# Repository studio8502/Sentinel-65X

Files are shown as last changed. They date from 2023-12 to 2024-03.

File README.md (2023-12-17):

# Sentinel 65X

This is a design for an 8/16-bit computer/games console, which uses
the 65816 CPU architecture (by WDC) and the VERA video system (by
Frank van den Hoef) as its core. It is not directly compatible with
any existing system, but porting from other 6502 and 65816 systems
which have a similar architecture should not prove difficult.

## Features

- Designed to minimize BOM and construction costs
- Intended to be a turnkey "fabrication ready" design which anyone
  can produce and sell for any purpose
- Fully open source hardware designs, released under the CERN OHL
  (permissive) V2
- 8MHz WDC W65C265S CPU (W65C816S compatible)
  - 16MB adress space
  - 8 timers
  - Multiple priority-encoded interrupts
  - Built-in GPIO
- 512KB of on-board static RAM
- 512KB of flash ROM
- RGB video output at 640x480
- Stereo audio output
- SD card slot
- Dual enhanced SNES-compatible controller ports
  - Supports SNES controllers & joysticks
  - Supports the SNES mouse and clones
  - Enhanced with I2C bus support for custom peripherals
- Cartridge/expansion port with full system bus, supporting ROM,
  RAM, and I/O expansions
- Amiga-inspired "clock port" which also serves as a debug port

## Hardware

The revision 0 schematic is nearly finished, approaching the production
of the first working prototypes. The goal is a limited release in 2024,
followed by a full release in 2025.

## Software

At the present time, software for this design is nonexistent. The
intention is to implement a kernel and library to support assembly
and C programming for cross-development (using the Calypsi C toolchain),
and to eventually develop or port a suite of tools for on-device
programming to be put into the system ROM.

The planned kernel will be reminiscent of the architecture of MSX-DOS
2, but will support long file names and the FAT32 (and later ExFAT)
filesystem on SD cards.

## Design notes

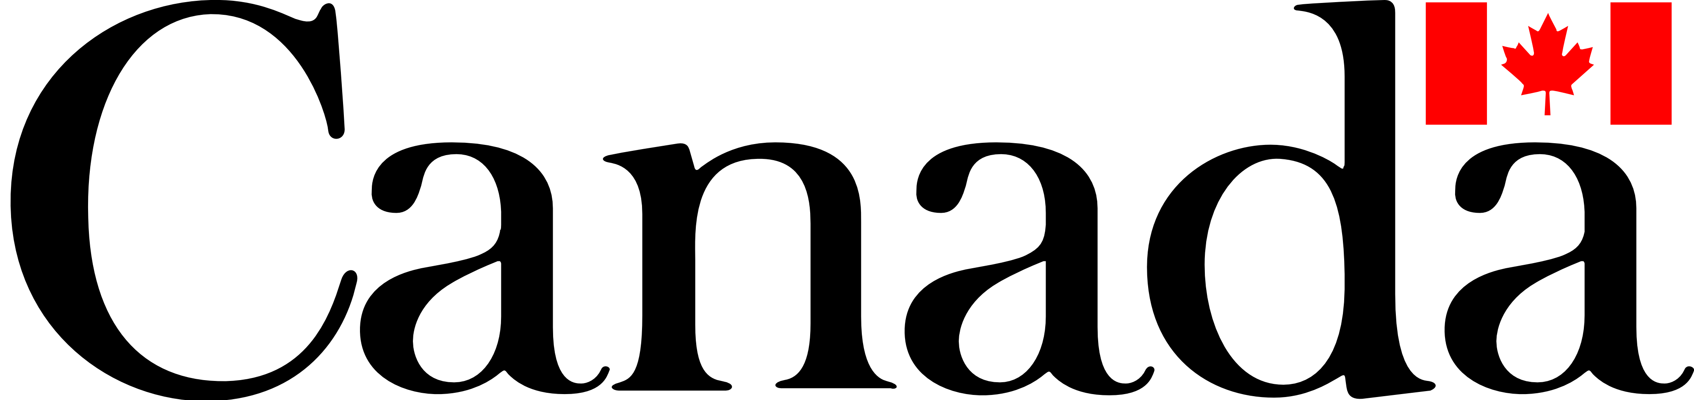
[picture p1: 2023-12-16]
Images/Canada_wordmark.png

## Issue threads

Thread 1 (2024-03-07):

Sentinal 65X - Prototype 4 Review

gsuberland, 2024-03-07:
## USB Power & Data (U7 / U8)

U8 appears to be improperly configured, with both 3V3OUT and U7 driving the +3.3V rail simultaneously. I suspect you were trying to set up the self-powered configuration in the FT230XS datasheet and accidentally connected 3V3OUT to the +3.3V rail instead of its own net. Based on the datasheet you probably want to connect 3V3OUT, VCCIO, and RESET together and then to a 100nF cap to ground. I suspect this is what C23 was initially supposed to be for. C23's +3.3V pad is also disconnected in the PCB design.

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

Decoupling on U8 is missing - should be 2x 100nF and 1x 4.7uF, all MLCCs as per Figure 6.2 of the datasheet.

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

The 27R series termination resistors on USB D+/D- lines are missing. See FT230X datasheet.

The FT230XS has a small amount of ESD protection so you can probably get away without any discrete ESD protection IC, but a TVS clamp on +5V (VBUS) wouldn't hurt.

The regulator layout is kinda loose and you've got pretty long loops with decoupling caps quite far from the things they're decoupling. There was also quite a bit of sketchy routing going on around there with non-ground stuff on the ground layer and unnecessary layer changes. I took the liberty of doing a bit of a tidy-up here since it was easier than trying to go through the details. Before and after:

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

Essentially I moved the caps closer to the things being decoupled, shifted the +5V trace from VBUS up and the 3.3V regulator right so the power traces are kept away from the USB D+/D- traces (and so the pins have a straight shot to the regulator input caps), did a similar thing with the output caps, then shortened the D+/D- traces significantly and eliminated the layer change on those signals, got rid of the 3V3 trace on the ground layer, and moved the D+/D- crossover trace under the connector to use F and In2 so the ground plane doesn't get broken and both stay referenced to the ground plane on In1. I've left the D-/D+ signals disconnected since you need to add the 27R termination resistors. Also note that I've left C23 in place as if it's a decoupling cap but you'll want to rework that when you fix the 3V3OUT stuff and add the three decoupling caps to U8.

I've attached the tweaked KiCad files :)

## Data lines

Wherever possible, each via that moves a signal from F or In1 to In3 or B should be accompanied by a ground stitching via placed as close as possible to that via, since the reference plane is changing from In1 to In4. This allows return currents to flow between the two ground planes, and provides a reference plane in the z-axis.

For example, all of these vias go from In2 to In3, which means the ground reference plane swaps from In1 to In4:

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

And here's how I'd add the reference vias: (sharing a ref via is fine)

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

## Processor

+3.3V pins on the east and south could be routed directly to the decoupling caps. East has a direct route without changing anything. South can be routed directly by shifting the RES trace down slightly.

I'd also consider swapping those 100nF caps for CL05A106MQ5NUNC (10uF 6.3V 0402). They're on JLCPCB Basic Parts, under half a cent each. After derating to 3.3V DC bias it's about 3.5uF. At 8MHz the caps have about 18mΩ of impedance, which is nice and low, mostly due to the smaller package size having lower inductance.

## Main RAM

C14 decoupling cap should be moved closer to the +3.3V pin. Again maybe upgrade to CL05A106MQ5NUNC.

## System ROM

Maybe upgrade C12 to CL05A106MQ5NUNC.

## SD Card Slot

If you're swapping other caps to CL05A106MQ5NUNC, you can save a BOM line by swapping C8 as well.

## Clock Generation

Again, probably CL05A106MQ5NUNC on the decoupling. Ideally move the caps so they sit across the +3.3V and GND pins on the ICs, rather than putting vias under the IC pads and under the cap pads.

For example, from this:

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

We can do this:

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

## VERA Graphics System

Missing decoupling on 5V output.

## Cartridge Port

Missing decoupling on 3.3V or 5.0V lines.

## Expansion Port

Missing decoupling on 3.3V or 5.0V lines.

## Clock Port

Missing decoupling on 3.3V line.

## Video DAC & Outputs

Missing decoupling on 3.3V line.

Unnecessary layer change on HSYNC line, could be routed all on In2.

## Audio DAC & Output

Missing decoupling caps. Probably some on the module, but I'd stick a 10uF MLCC on the 5V line anyway.

Are A3V3 and AGND disconnected on purpose? The PCM5102 IC datasheet shows them connected to +3.3V and ground, but maybe there's something specific about the GY-PCM5102 module board I don't know?

## Controller Ports

Missing decoupling caps.

## Glue Logic

Atmel appnote 0484C–09/99 recommends 220nF capacitance with 4nH parasitic inductance at most, so a pair of 100nF 0805s are probably not gonna cut it. I'd recommend replacing C14/C15 for a single CL05B224KO5NNNC 220nF 16V 0402 capacitor.

joelpmichael, 2024-03-08:
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

I'm still not liking the smell of this section. I've seen problems with a UART's 3V3 LDO line hooked to the host board's 3V3 rail, where a sudden current use spike reliably caused the UART to crash.  In this case it may not be a problem due to VCC being 3.3V (the board I had an issue with had VCC connected to USB-VBUS in parallel with a 3.3V LDO), but if anything it would be more correct to use USB-VBUS directly to power the UART because there's no other power supply for the UART (yet?)

You may want to go back to the LM1085 from V4 as the voltage regulator between USB-VBUS and 3V3, because it has a higher current rating than a '1117 and it saves you a BOM line.  Alternatively, you could do something like add a buck regulator to v4's power input to bring that down to about 5V (and avoid a lot of heat from the 5V LDO), and power diodes between USB-VBUS and the buck-regulated 5V rail.

gsuberland, 2024-03-08:
Additional thoughts:

## 3V3OUT

Good idea to use 0R / jumper footprints to give you the option to revert it back to the tie-to-ground instead of tie-to-3V3 appreoach. That way if it doesn't work you don't need a respin.

## Voltage Regulators

The 10uF input cap is at the absolute limit of the USB spec for bus capacitance. If it's got 20% tolerance, you're potentially exceeding the spec. If it's a cheaper cap with -20%/+80% tolerance, you're potentially vastly exceeding the spec. I'd recommend swapping it for a 4.7uF electrolytic or tantalum. Probably not best to use an MLCC because its very low ESR means higher inrush current and potential resonance issues when combined with the USB cable's inductance, but you can probably get away with it fine as long as you don't want to sell this as a product (where it'll need to pass EMC).

The 10uF electrolytic output cap is probably not the best choice now I've had time to mull it over. A pair of 10uF tantalum caps (TAJA106K016RNJ) are a better option, or you could go with a pair of the 10uF MLCCs I recommended (which would be cheaper). This choice gets a bit tricky because AMS1117, LM1117, and AP1117 have different behaviours on this front. Check your LDO's datasheet to see if it mentions being stable with MLCCs only, and what the specific decoupling advice is. AMS1117, for example, says 22uF tantalum is ideal, so 2x 10uF tantalum should be fine. Often LDO vendors recommend doubling the capacitance (e.g. 47uF instead of 22uF) if you're using electrolytics, but you should follow datasheet / appnote guidance here.

## Video DAC

The UPduino IOs are used to drive the resistor ladder DAC, but those resistances are quite low so the IO current might be excessive for the FPGA. I wasn't able to find any IO current limit specs for the ICE40UP5K, so I'm not 100% sure. However, in the worst case (input lines 0, 1, and 2 low, and line 3 high, and assuming worst-case 5% tolerance on the resistors) the draw will be 5.47mA with 5V IO or 3.61mA with 3.3V IO. In the absence of information showing that the FPGA can handle that much IO current, it would be a good idea to use a buffer IC (a pair of hex CMOS buffers would do it) on the R0-R3, G0-G3, and B0-B3 lines to ensure that the IOs can provide enough current.

I'm not sure what frequency you're updating the DAC input signals at, so make sure the buffer IC is rated for it. Most modern CMOS buffer ICs should be fine.

It's also worth adding opamp buffers on the red, green, and blue outputs. This will make the outputs immune to leakage current, so you'll get correct R/G/B voltage levels on the SVGA output regardless of what display you plug in. Make sure the opamps are RRIO (rail-to-rail input and output) capable (or at least capable of going right down to 0V), and unity gain stable. Make sure the opamps have sufficient bandwidth and slew rate for the signal update rate.

If you have space, it might be worth adding a separate LDO for powering the output opamps, to make sure they have a nice clean rail. Again follow the decoupling advice on the LDO datasheet. You can get away without this but it adds peace of mind.

I'm also not a fan of the naming of the RGB signals, 'cos R2 (the signal) and R2 (the part) are ambiguous. Maybe prefix the signals with V, e.g. VR1.

## USB IOs

Not sure about those 270R on the TXD/RTS lines. I don't see them in the datasheet and I'm not sure what purpose they serve here.

Might be worth adding [the TX/RX swap footprint trick](https://hachyderm.io/@mwbrown/111903245384095180) to both the TXD/RXD lines on the MCU side and the D+/D- lines on the USB connector side. Use 0603 or 0402 on the D+/D- side to avoid a large impedance discontinuity.

# General

There's a lack of testpoints on the PCB. Don't forget to add them for easier debug. I also like adding a large plated ground pad right on the edge of the board somewhere, top and bottom, connected to ground, so I can clip a crocodile clip to the edge of the board really easily while probing.

I also recommend separating critical power and signal paths with SMD jumper pads or 0R footprints at the boundary between different blocks of the circuit. This allows you to isolate and test each block of the circuit sequentially and catch / debug issues early instead of just powering the lot on and praying for no magic smoke. For example I might add a 0R between VUSB and the LDO input, and then again between the LDO and the 3V3 rail. Wherever you think you might benefit from being able to turn one thing on at once, or disable something, or disconnect some signal for debugging. This also allows you to stick a shunt resistor inline with the voltage rails if you want to measure the rail current.

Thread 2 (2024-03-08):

Repo incompability with Windows

joelpmichael, 2024-03-08:
Error while checking out repo due to `:` being a reserved character in file paths on Windows.

```
$ git clone https://github.com/studio8502/Sentinel-65X.git
Cloning into 'Sentinel-65X'...
remote: Enumerating objects: 406, done.
remote: Counting objects: 100% (224/224), done.
remote: Compressing objects: 100% (157/157), done.
remote: Total 406 (delta 73), reused 212 (delta 63), pack-reused 182
Receiving objects: 100% (406/406), 133.68 MiB | 12.91 MiB/s, done.
Resolving deltas: 100% (156/156), done.
error: invalid path 'kicad/A:V Boards/DVI (256 colours) + Stereo Miniplug/DVI (2
56 colours) + Stereo Miniplug-backups/DVI (256 colours) + Stereo Miniplug-2024-0
2-26_213444.zip'
fatal: unable to checkout working tree
warning: Clone succeeded, but checkout failed.
You can inspect what was checked out with 'git status'
and retry with 'git restore --source=HEAD :/'
```

You may want to add .DS_Store to your .gitignore too.

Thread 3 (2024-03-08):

Prototype 3/4/4A review

joelpmichael, 2024-03-08:
As commented in #1 you should think more about your overall power supply now that you're also adding USB power, including making sure you aren't back-powering either the barrel jack (J10 in V4) or USB-VBUS if both are connected.  I've used this setup successfully:
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

The other potential issue I can see, that's been repeated over the entire design, is that connector shields are not grounds if there's ground pins inside the connector! [Microchip AN2587](https://www.microchip.com/en-us/application-notes/an2587-1.html) is a good place as any to start when diving down this infinite chasm, specifically section 12.3. The (ex-Atmel) Microchip SAM datasheets also contain an excellent schematic checklist, including a checklist item about ESD protection.  The [SAML21 Family Datasheet](https://ww1.microchip.com/downloads/aemDocuments/documents/MCU32/ProductDocuments/DataSheets/SAM-D21-DA1-Family-Data-Sheet-DS40001882H.pdf) section 45.8 discusses ESD and correct grounding protection of USB connectors. This is part of the same system with the example buck-boost regulator, and includes a dedicated (yet extremely cheap because it's so common) USB ESD protection system:
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

KyleCardoza, 2024-03-08:
Far as the first bit goes, there won't be a barrel jack to back-power, so no worries there. I will look at that recommended documentation, but have already fixed the shield bit, I think:

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

KyleCardoza, 2024-03-08:
(ignore that disconnected D+ line, I just fixed it)

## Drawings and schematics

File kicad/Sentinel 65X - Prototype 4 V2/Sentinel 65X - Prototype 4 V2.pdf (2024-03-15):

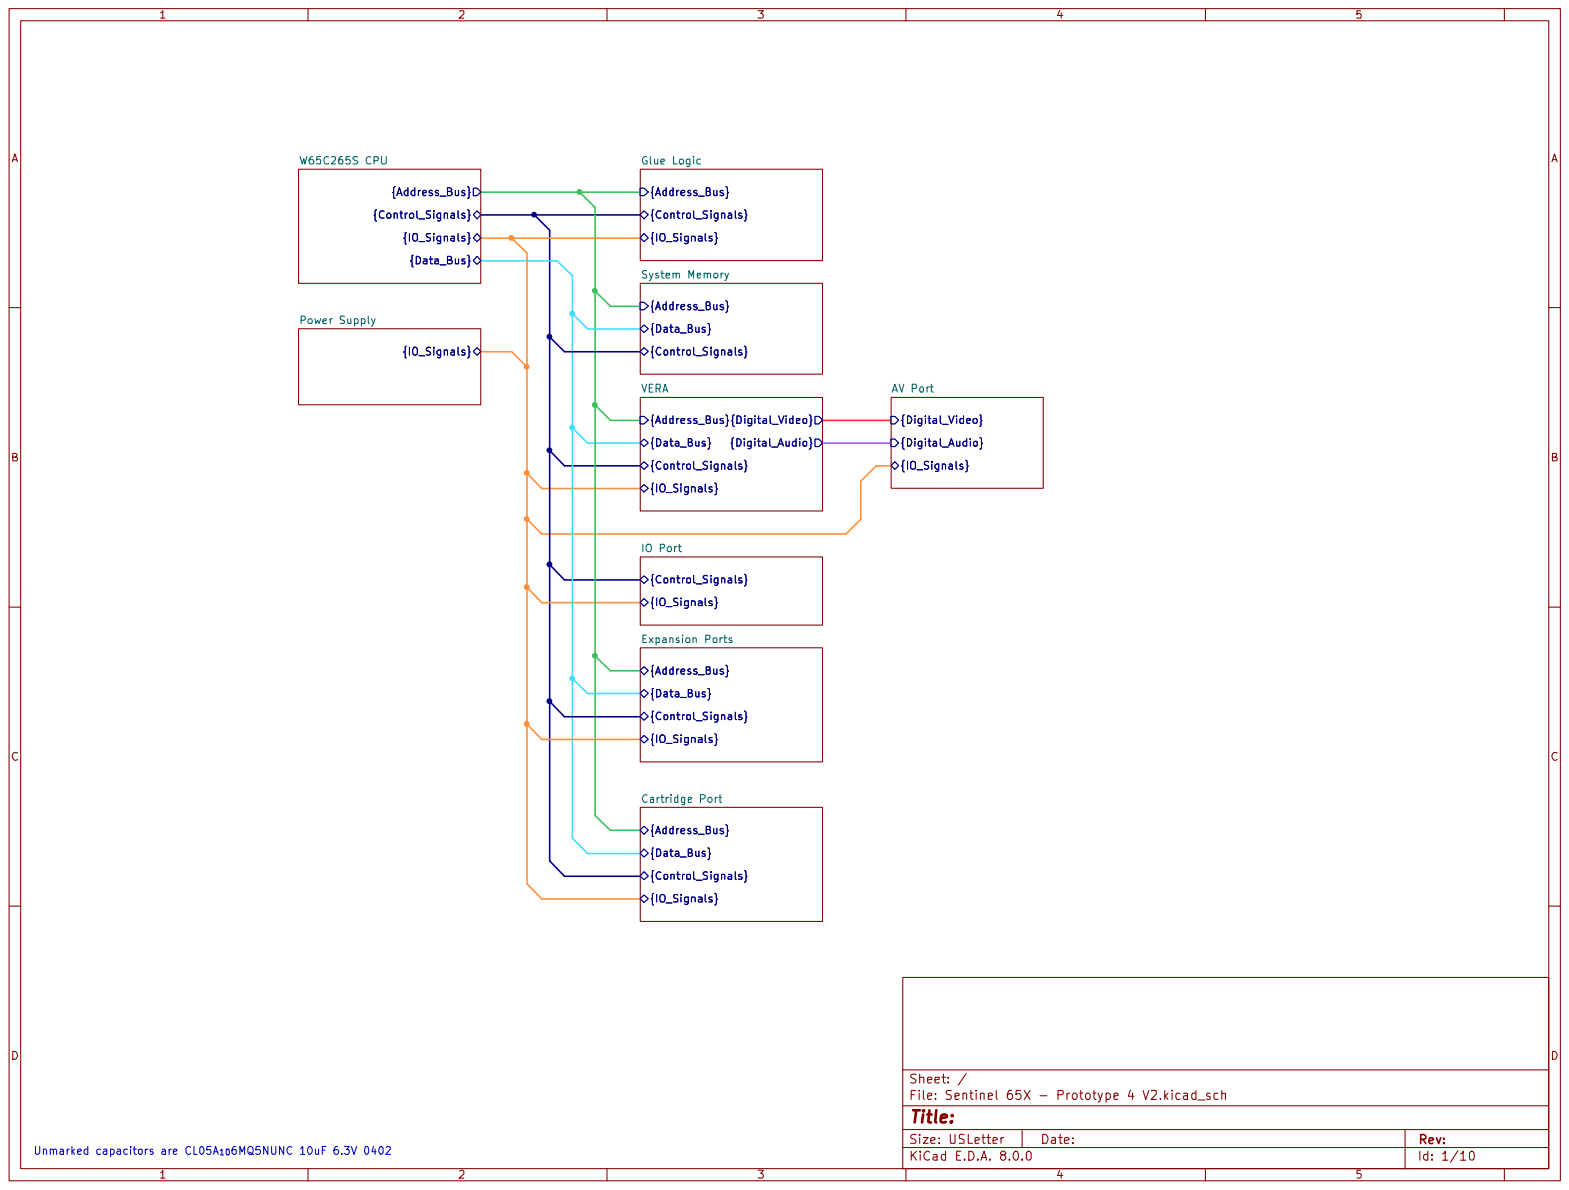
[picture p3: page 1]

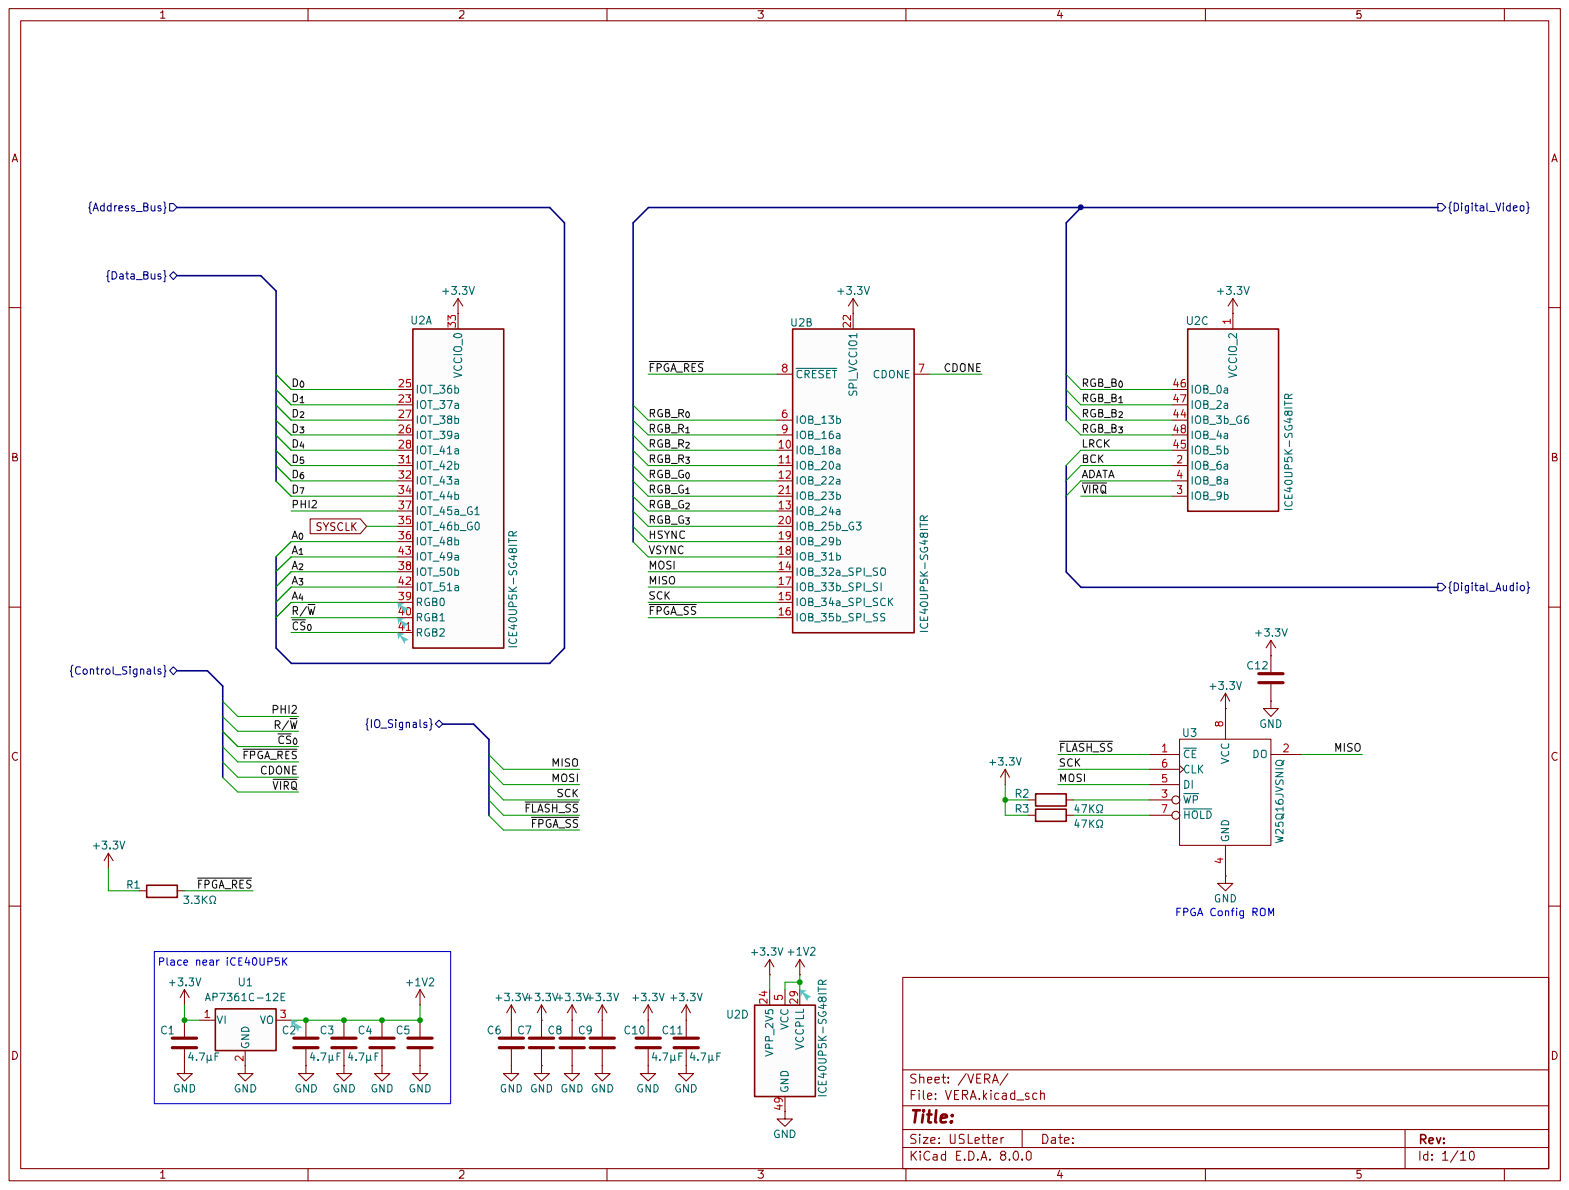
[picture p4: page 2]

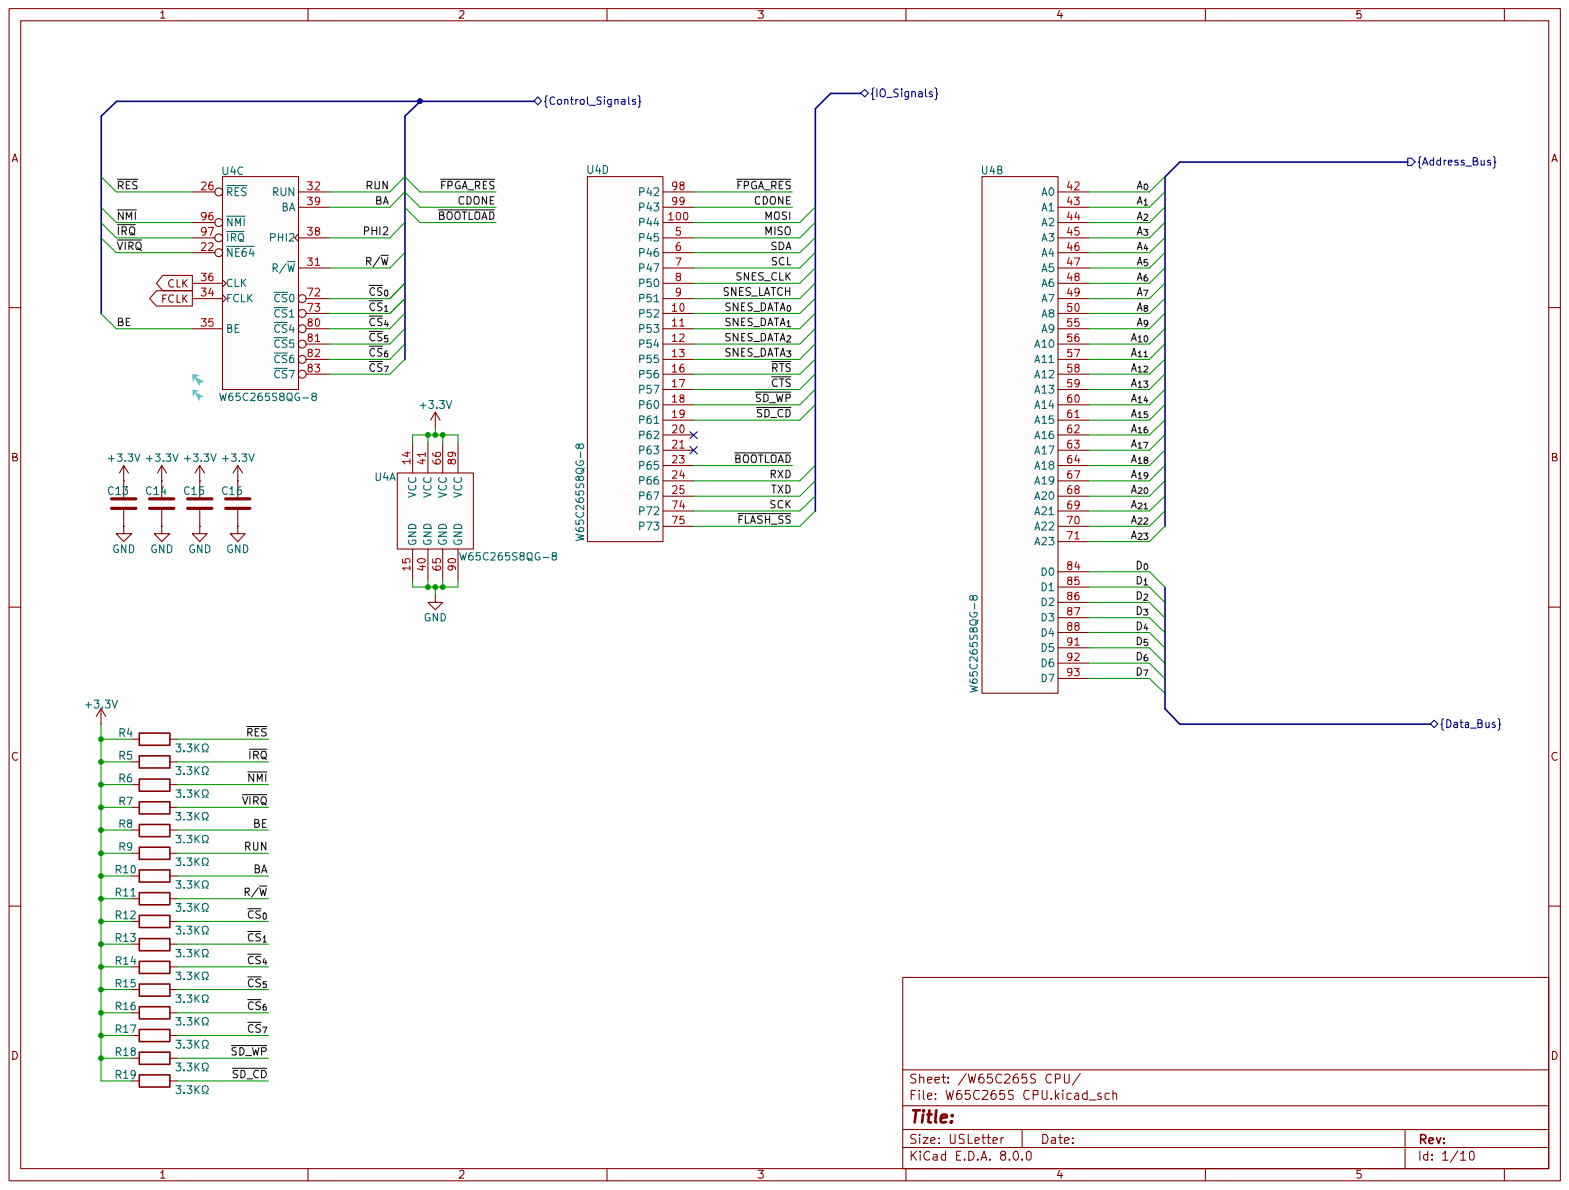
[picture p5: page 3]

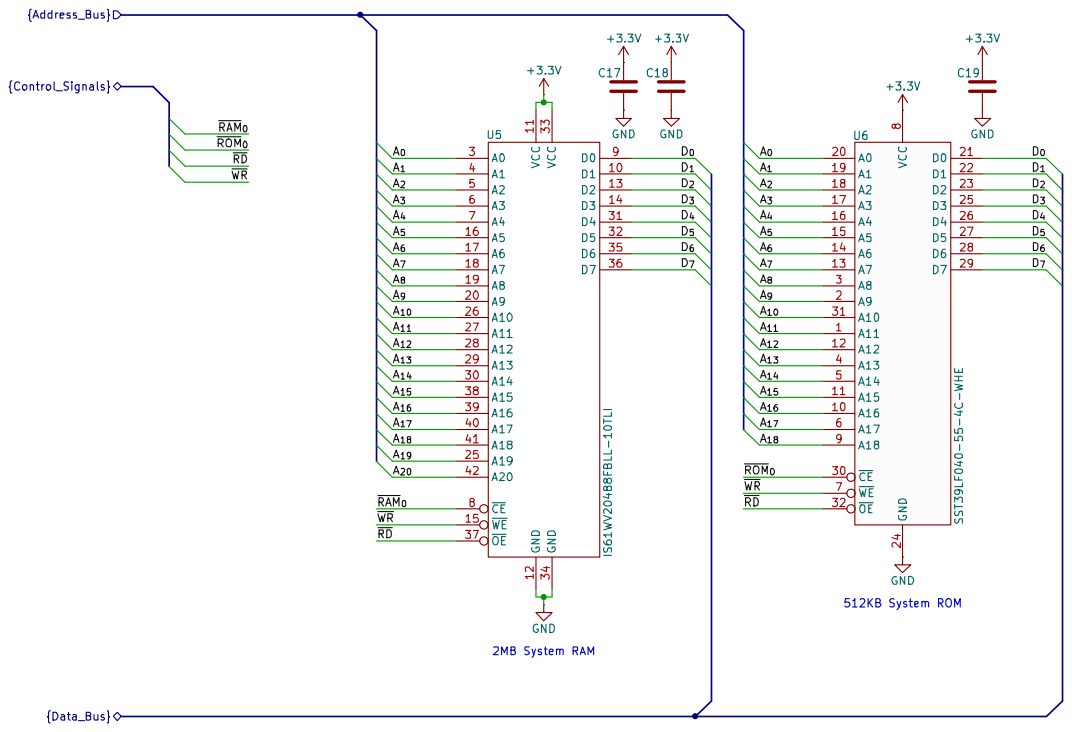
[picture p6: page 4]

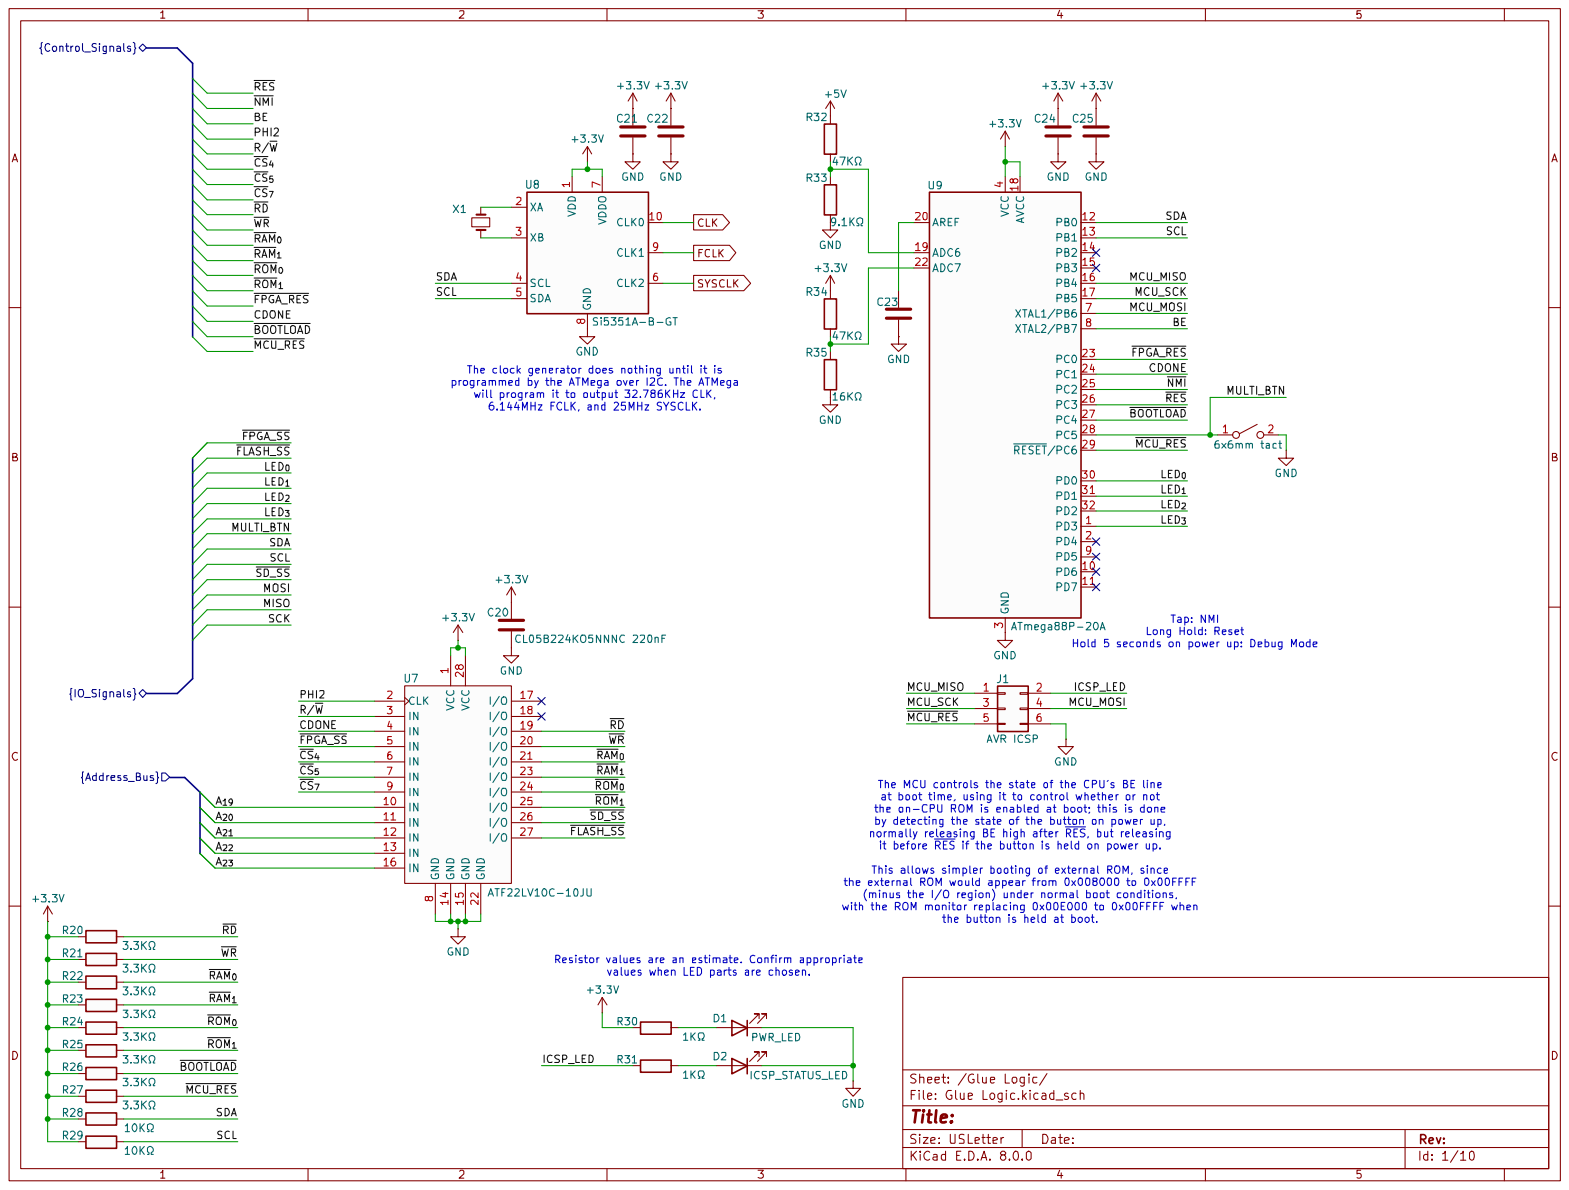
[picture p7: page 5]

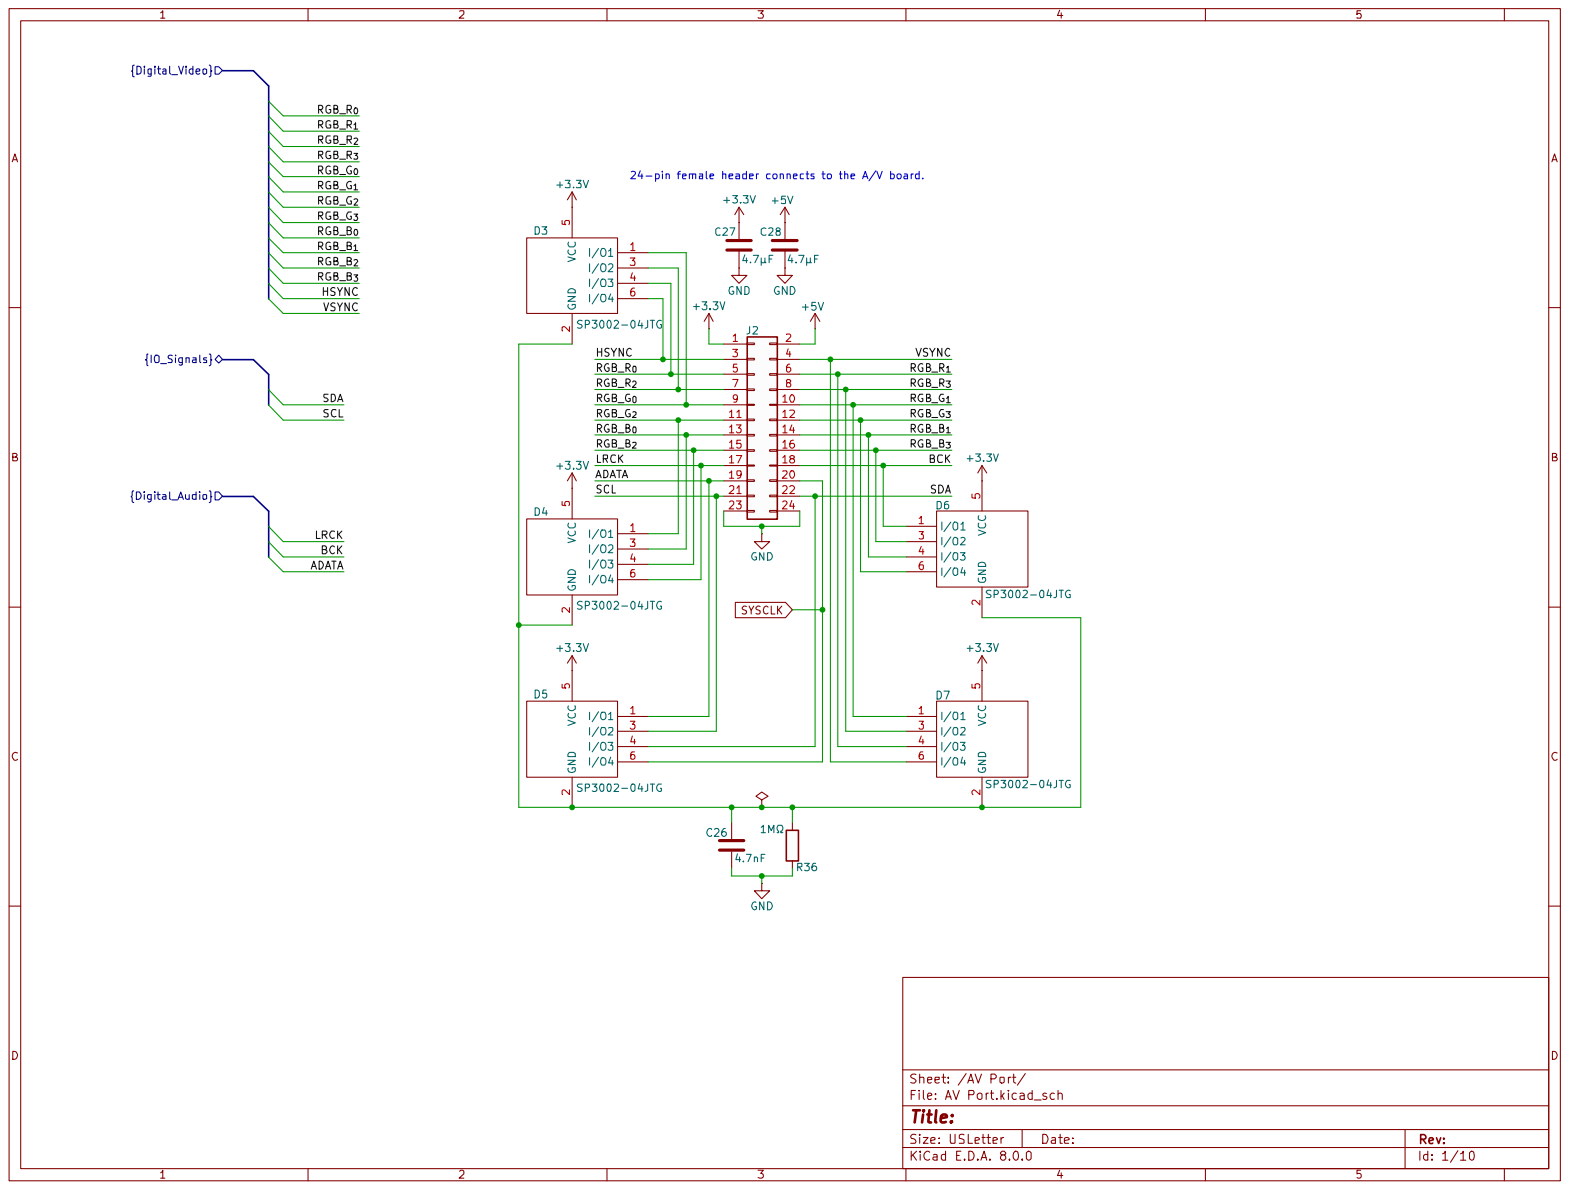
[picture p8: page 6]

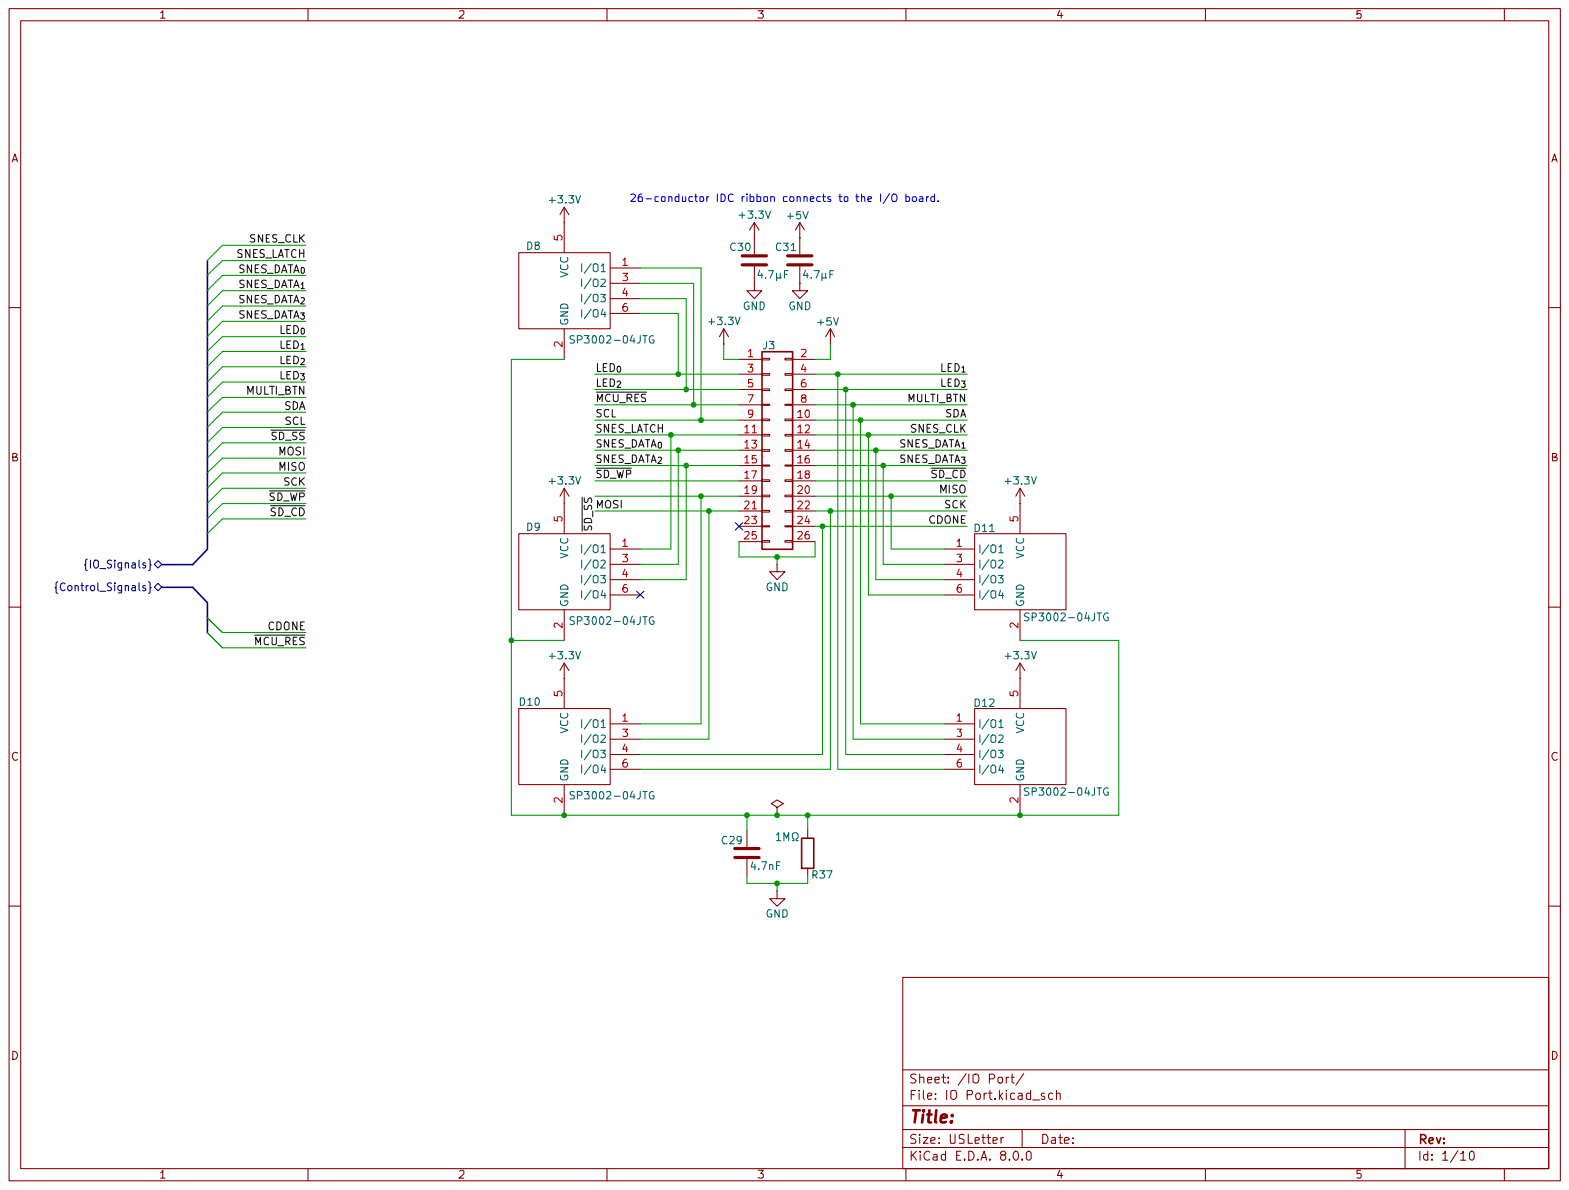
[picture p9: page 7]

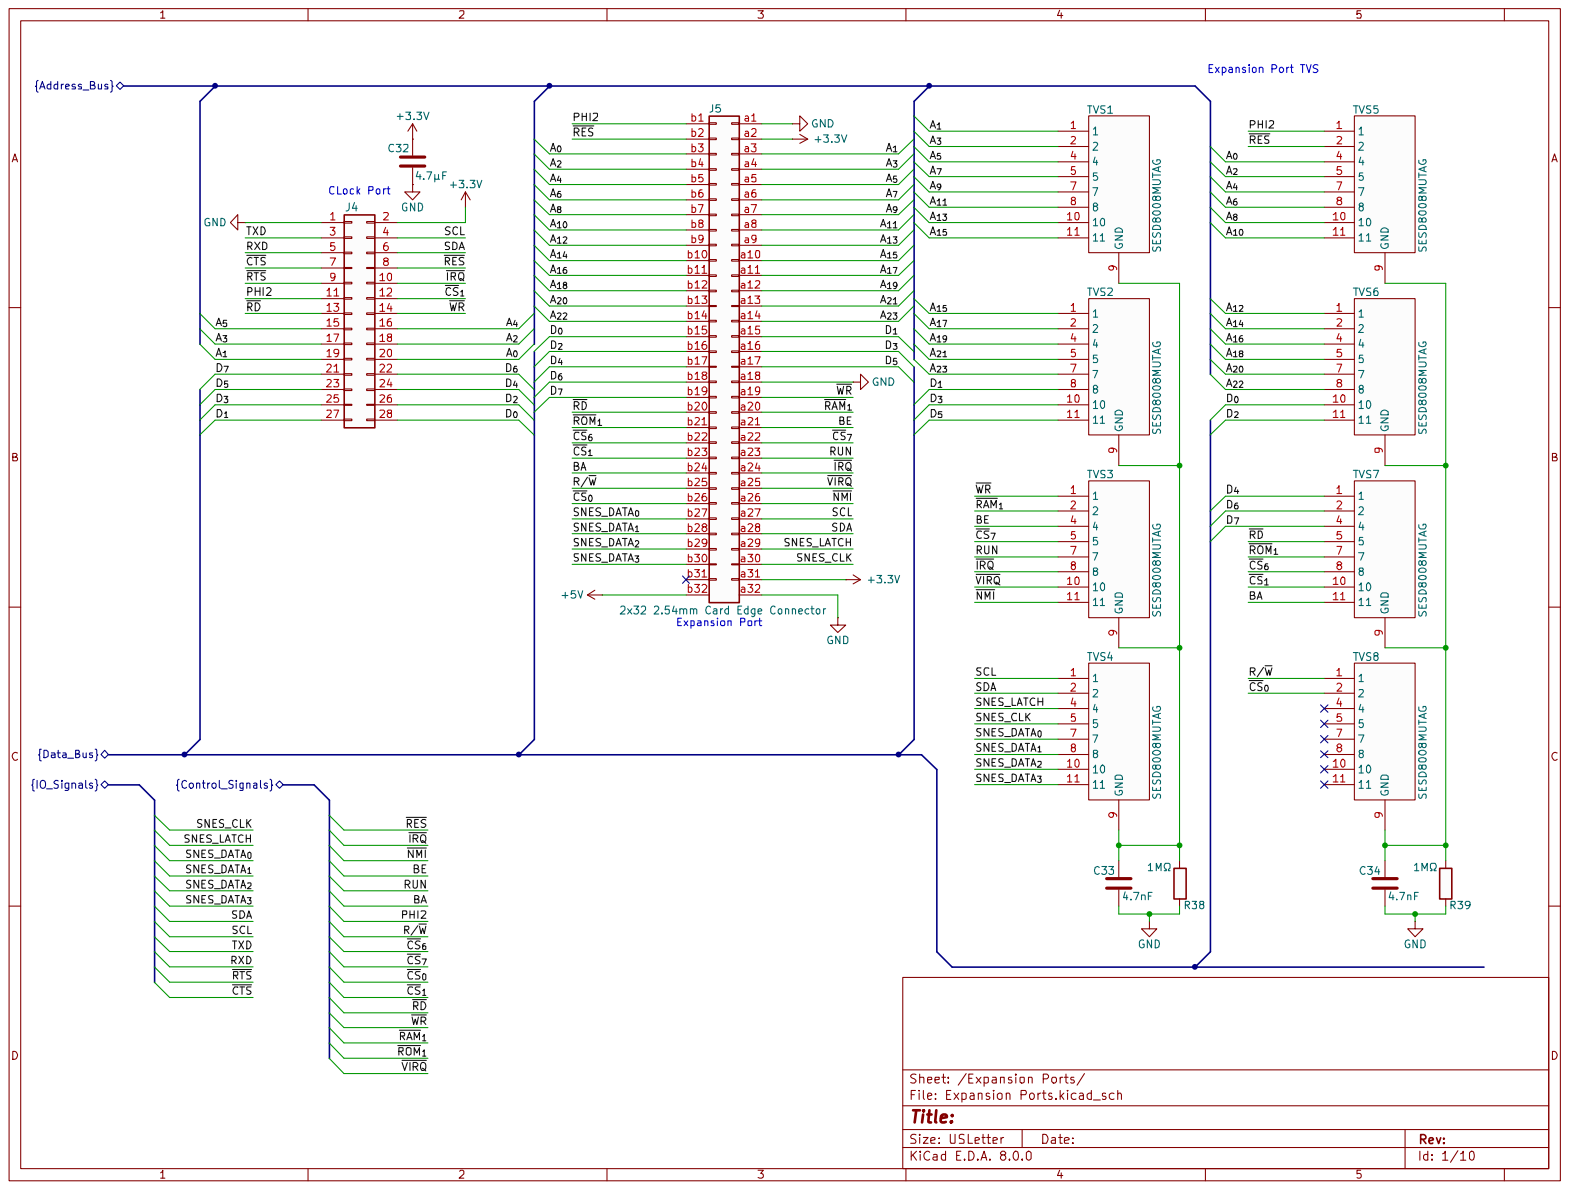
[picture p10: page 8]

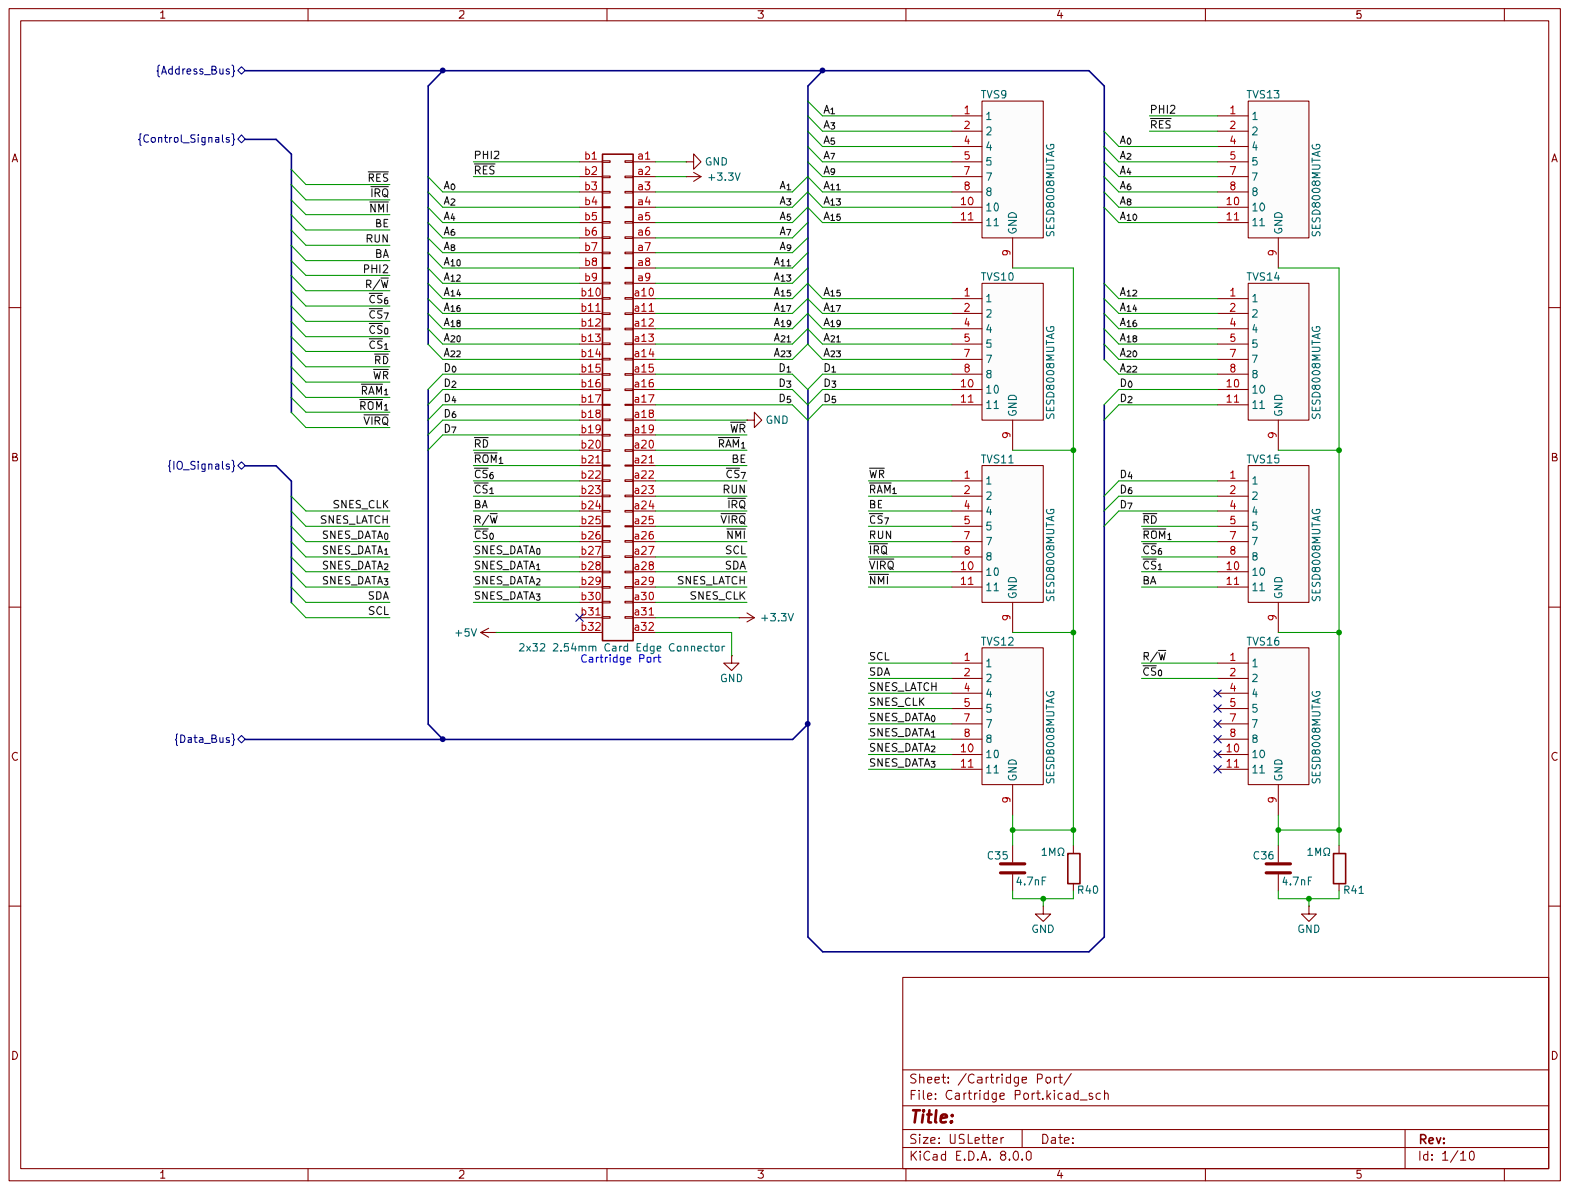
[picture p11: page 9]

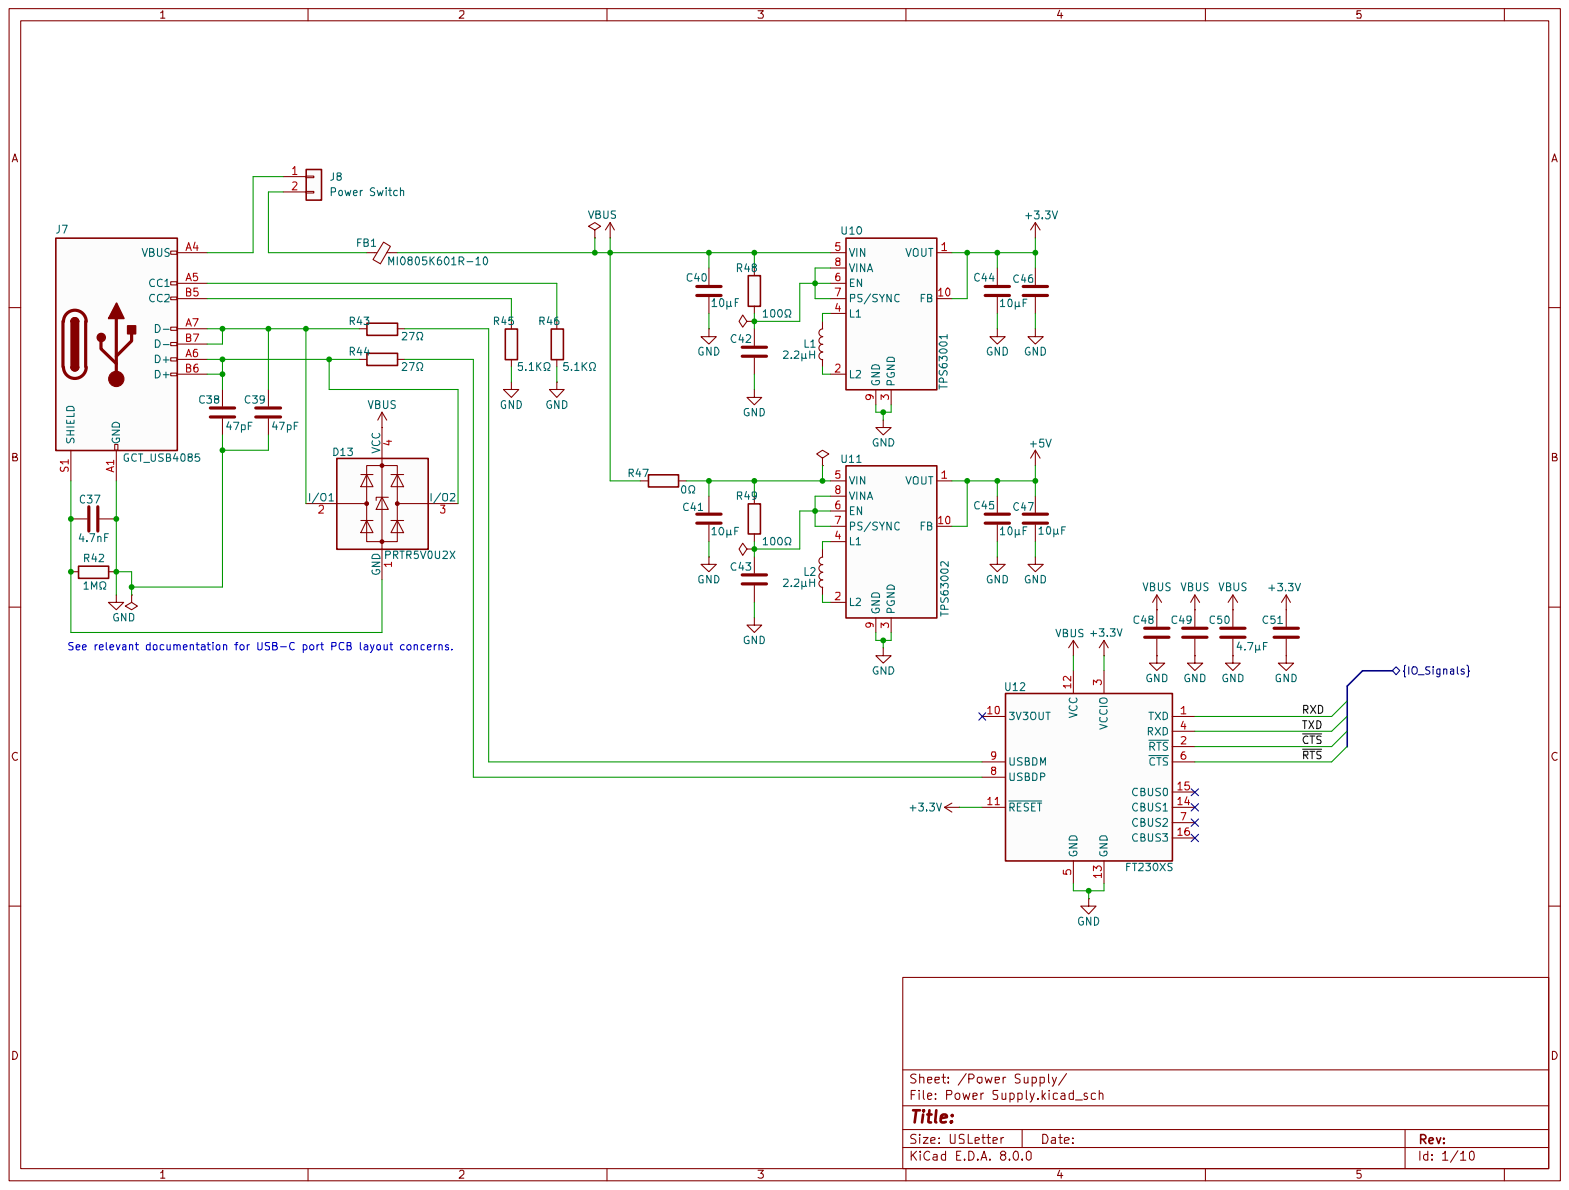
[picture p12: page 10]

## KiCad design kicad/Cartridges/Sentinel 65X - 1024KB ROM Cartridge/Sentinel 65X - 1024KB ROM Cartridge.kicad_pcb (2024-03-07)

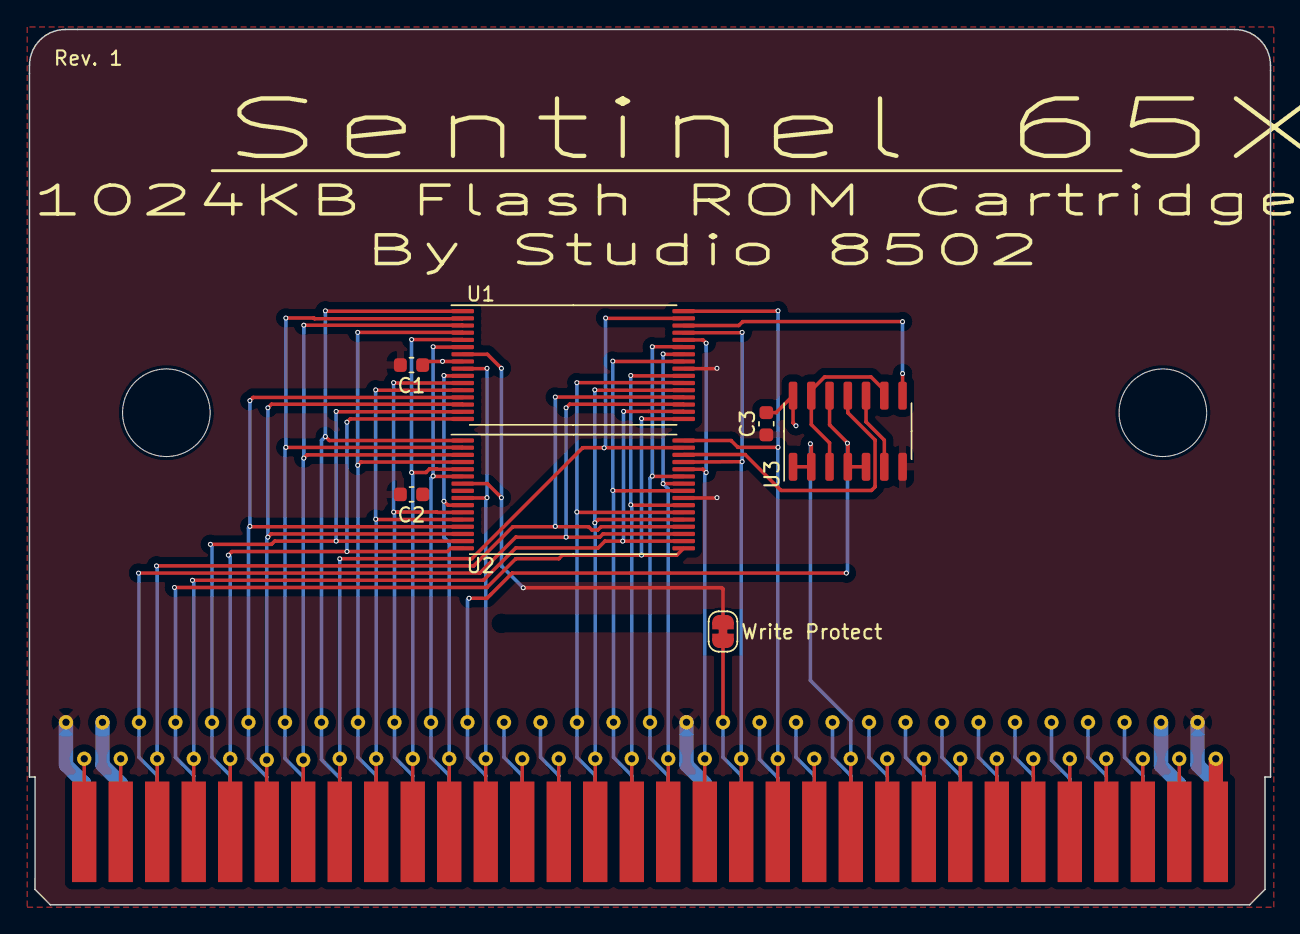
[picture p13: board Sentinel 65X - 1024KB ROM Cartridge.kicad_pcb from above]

Board: 2 copper layers, 86.4 x 60.9 mm, 8 parts (0 on the bottom side), 38 nets.

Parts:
C1, C2, C3: 100nF; C_0603_1608Metric
J1: 2x32 2.54mm Card Edge Connector; Conn_Edge_2x32_THT_2.54mm_Male
JP1: SolderJumper_2_Bridged; SolderJumper-2_P1.3mm_Bridged_RoundedPad1.0x1.5mm
U1, U2: TSOP-I-32_14.4x8mm_P0.5mm
U3: 74LS00; SOIC-14_3.9x8.7mm_P1.27mm

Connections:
+3.3V: C1.1, C2.1, C3.1, J1.a2, J1.a31, U1.8 (VDD), U2.8 (VDD), U3.14 (VCC)
/A0: J1.b30, U1.20 (A0), U2.20 (A0)
/A1: J1.a30, U1.19 (A1), U2.19 (A1)
/A2: J1.b29, U1.18 (A2), U2.18 (A2)
/A3: J1.a29, U1.17 (A3), U2.17 (A3)
/A4: J1.b28, U1.16 (A4), U2.16 (A4)
/A5: J1.a28, U1.15 (A5), U2.15 (A5)
/A6: J1.b27, U1.14 (A6), U2.14 (A6)
/A7: J1.a27, U1.13 (A7), U2.13 (A7)
/A8: J1.b26, U1.3 (A8), U2.3 (A8)
/A9: J1.a26, U1.2 (A9), U2.2 (A9)
/A10: J1.b25, U1.31 (A10), U2.31 (A10)
/A11: J1.a25, U1.1 (A11), U2.1 (A11)
/A12: J1.b24, U1.12 (A12), U2.12 (A12)
/A13: J1.a24, U1.4 (A13), U2.4 (A13)
/A14: J1.b23, U1.5 (A14), U2.5 (A14)
/A15: J1.a23, U1.11 (A15), U2.11 (A15)
/A16: J1.b22, U1.10 (A16), U2.10 (A16)
/A17: J1.a22, U1.6 (A17), U2.6 (A17)
/A18: J1.b21, U1.9 (A18), U2.9 (A18)
/A19: J1.a21, U3.4, U3.5, U3.12
/D0: J1.b18, U1.21 (D0), U2.21 (D0)
/D1: J1.a18, U1.22 (D1), U2.22 (D1)
/D2: J1.b17, U1.23 (D2), U2.23 (D2)
/D3: J1.a17, U1.25 (D3), U2.25 (D3)
/D4: J1.b16, U1.26 (D4), U2.26 (D4)
/D5: J1.a16, U1.27 (D5), U2.27 (D5)
/D6: J1.b15, U1.28 (D6), U2.28 (D6)
/D7: J1.b14, U1.29 (D7), U2.29 (D7)
/~CS6: J1.b11, U3.1, U3.2
/~RD: J1.b13, U1.32 (~OE), U2.32 (~OE)
/~ROMH: U2.30 (~CE), U3.11
/~ROML: U1.30 (~CE), U3.8
/~WR: JP1.2 (B), U1.7 (~WE), U2.7 (~WE)
GND: C1.2, C2.2, C3.2, J1.a1, J1.a15, J1.a32, U1.24 (GND), U2.24 (GND), U3.7 (GND)
unnamed: J1.a14, JP1.1 (A)
unnamed: U3.6, U3.10
unnamed: U3.3, U3.9, U3.13

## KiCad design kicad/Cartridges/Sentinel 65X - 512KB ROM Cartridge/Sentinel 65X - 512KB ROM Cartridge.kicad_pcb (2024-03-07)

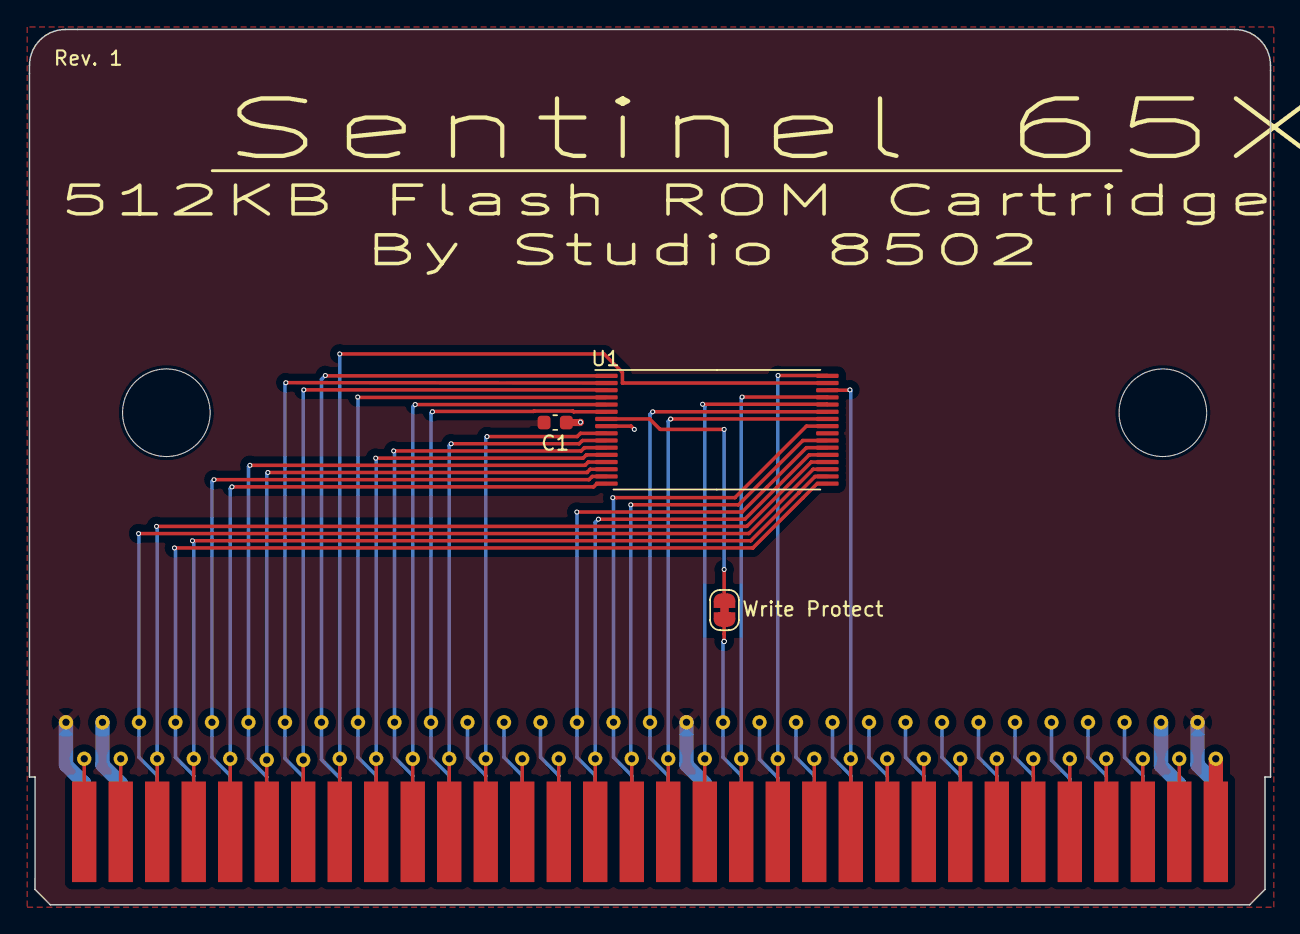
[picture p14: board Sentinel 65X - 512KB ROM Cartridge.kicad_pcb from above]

Board: 2 copper layers, 86.4 x 60.9 mm, 4 parts (0 on the bottom side), 33 nets.

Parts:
C1: 100nF; C_0603_1608Metric
J1: 2x32 2.54mm Card Edge Connector; Conn_Edge_2x32_THT_2.54mm_Male
JP1: SolderJumper_2_Bridged; SolderJumper-2_P1.3mm_Bridged_RoundedPad1.0x1.5mm
U1: TSOP-I-32_14.4x8mm_P0.5mm

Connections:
+3.3V: C1.1, J1.a2, J1.a31, U1.8 (VDD)
/A0: J1.b30, U1.20 (A0)
/A1: J1.a30, U1.19 (A1)
/A2: J1.b29, U1.18 (A2)
/A3: J1.a29, U1.17 (A3)
/A4: J1.b28, U1.16 (A4)
/A5: J1.a28, U1.15 (A5)
/A6: J1.b27, U1.14 (A6)
/A7: J1.a27, U1.13 (A7)
/A8: J1.b26, U1.3 (A8)
/A9: J1.a26, U1.2 (A9)
/A10: J1.b25, U1.31 (A10)
/A11: J1.a25, U1.1 (A11)
/A12: J1.b24, U1.12 (A12)
/A13: J1.a24, U1.4 (A13)
/A14: J1.b23, U1.5 (A14)
/A15: J1.a23, U1.11 (A15)
/A16: J1.b22, U1.10 (A16)
/A17: J1.a22, U1.6 (A17)
/A18: J1.b21, U1.9 (A18)
/D0: J1.b18, U1.21 (D0)
/D1: J1.a18, U1.22 (D1)
/D2: J1.b17, U1.23 (D2)
/D3: J1.a17, U1.25 (D3)
/D4: J1.b16, U1.26 (D4)
/D5: J1.a16, U1.27 (D5)
/D6: J1.b15, U1.28 (D6)
/D7: J1.b14, U1.29 (D7)
/~CS6: J1.b11, U1.30 (~CE)
/~RD: J1.b13, U1.32 (~OE)
/~WR: J1.a14, JP1.1 (A)
GND: C1.2, J1.a1, J1.a15, J1.a32, U1.24 (GND)
unnamed: JP1.2 (B), U1.7 (~WE)

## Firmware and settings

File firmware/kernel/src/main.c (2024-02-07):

//*****************************************************************************
//  Turaco-DOS
//
//  src/kernel/main.c
//*****************************************************************************

#include "config.h"
#include "turaco.h"

#include "kernel/device.h"

void
main(void)
{
	device_init_all();

	for (;;) {}
}

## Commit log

2023-12-06 Initial import of work in progress
    [Sentinel 65.kicad_pcb, Sentinel 65.kicad_sch, cpu.kicad_sch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]
2023-12-07 More work in progress
    [Sentinel 65.kicad_sch, audio_output.kicad_sch, io_connectors.kicad_sch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]
2023-12-14 Catchup to Rev0, V2
    [Sentinel 65 V2.kicad_pcb, Sentinel 65 V2.kicad_sch, Sentinel 65.kicad_pcb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]
2023-12-14 Added PDF of schematic
    [Sentinel 65 V2.kicad_sch]
2023-12-14 Added datasheets and manuals
    [Sentinel 65 V2.kicad_sch]
2023-12-15 Pinouts updated
    [Sentinel 65 V2.kicad_sch]
2023-12-16 Added audio mixing of cartridge audio
    [Sentinel 65 V2.kicad_sch]
2023-12-16 logo import
    [Sentinel 65 V2.kicad_pcb, Sentinel 65 V2.kicad_sch]
2023-12-16 Updated schematic PDF
    [Sentinel 65 V2.kicad_pcb, Sentinel 65 V2.kicad_sch]
2023-12-16 Updated license terms
    [Sentinel 65 V2.kicad_pcb, Sentinel 65 V2.kicad_sch]
2023-12-17 Added programmable clock generator
    [Sentinel 65 V2.kicad_sch]
2023-12-18 Switched glue logic to ATF1502 TQFP-44, added JTAG header
    [Sentinel 65 V2.kicad_sch]
2023-12-18 Removed DV header, deferred to Rev1. Updated PDF schematic.
    [Sentinel 65 V2.kicad_sch]
2023-12-18 Added project-specific library
    [Sentinel 65 V2.kicad_sch]
2023-12-19 Added FPGA CDONE and reset pins to CPU GPIO. Added CDONE indicator LED.
    [Sentinel 65 V2.kicad_sch]
2023-12-19 Added FPGA pins CDONE and RESET to the clock port.
    [Sentinel 65 V2.kicad_sch]
2023-12-19 Adjusted VERA pinout for initial routing of Rev0 PCB
    [Sentinel 65 V2.kicad_pcb, Sentinel 65 V2.kicad_sch, Sentinel 65X V2.kicad_pcb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]
2023-12-19 Updated Rev0 schematic PDF
2023-12-19 Updated pinouts
    [Sentinel 65X V2.kicad_sch]
2023-12-23 Updated schematic to add RTS/CTS flow control to debug UART (required by CPU's on-chip ROM monitor)
    [Sentinel 65X V2.kicad_sch]
2024-02-07 Added version 3 and 4 prototype schematics
    [Sentinel 65X - PTH Prototype 2.kicad_pcb, Sentinel 65X - PTH Prototype 2.kicad_sch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]
2024-03-07 Updated schematics and PCB files for prototype 4
    [CPU.kicad_sch, DVI (256 colours) + Stereo Miniplug.kicad_pcb, DVI (256 colours) + Stereo Miniplug.kicad_sch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]
2024-03-15 Updated prototype 4 V2 schematic
    [AV Port.kicad_sch, Basic IO Board.kicad_pcb, Basic IO Board.kicad_sch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]
2024-03-17 Updated prototype 4V2 schematic
    [AV Port.kicad_sch, Cartridge Port.kicad_sch, Expansion Ports.kicad_sch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]
